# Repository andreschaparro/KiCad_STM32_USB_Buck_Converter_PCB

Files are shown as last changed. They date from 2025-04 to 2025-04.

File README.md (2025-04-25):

# KiCad STM32 + USB + Buck Converter PCB Design and JLCPCB Assembly

## Links

- [Fabricante de PCB](https://jlcpcb.com/).
- [Componentes](https://jlcpcb.com/parts).
- [Microcontrolador STM32 F4](https://jlcpcb.com/partdetail/Stmicroelectronics-STM32F405RGT6/C15742).
- [Conversor Buck](https://jlcpcb.com/partdetail/Monolithic_PowerSystems-MP2359DJ_LFZ/C14259).
- [Protección ESD para el USB](https://jlcpcb.com/partdetail/Stmicroelectronics-USBLC62SC6/C7519).
- [Cristal 16Mhz](https://jlcpcb.com/partdetail/Yxc_CrystalOscillators-X322516MLB4SI/C13738).
- [Protección Polaridad Inversa](https://jlcpcb.com/partdetail/Alpha_OmegaSemicon-AO3401A/C15127).
- [Ferrite para Conversores Buck](https://jlcpcb.com/partdetail/Sunlord-GZ2012D601TF/C1017).
- [Diodo Schottky recomendado para Conversores Buck](https://jlcpcb.com/partdetail/mdd_microdiode_semiconductor-B5819W/C64885).
- [Inductor de potencia para Conversores Buck](https://jlcpcb.com/partdetail/Sunlord-MWSA0503S100MT/C408412).

❗Minimizar el uso de extended parts y usar las basic para minimizar el costo del PCB.

## STM32CubeIDE

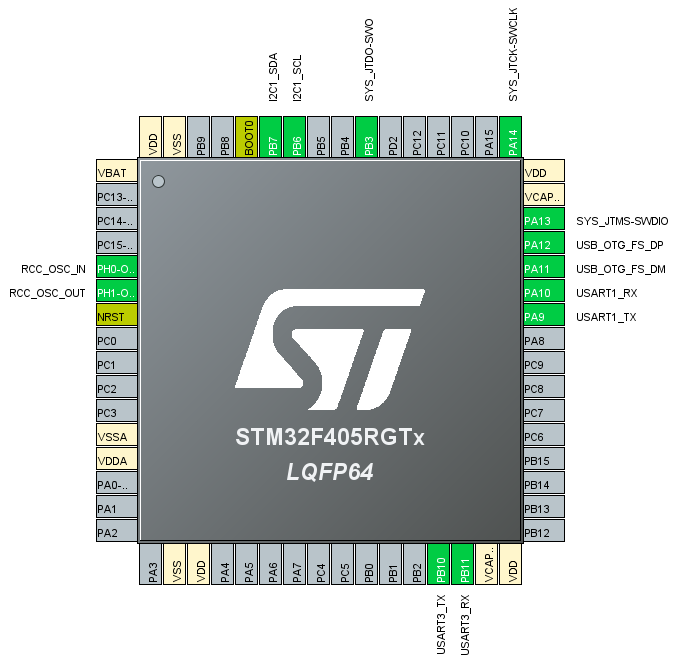
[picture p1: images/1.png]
Mala posición de la USART1


📝En lo posible, colocar los buses de comunicación en distintos laterales del microcontrolador. Y si no se puede, colocarlos lo mas separados que se pueda dentro del mismo lateral.

❗En la imagen, se ve una mala ubicación para la USART1 porque queda muy cerca del USB_FS. Para solucionar el problema, utilizar la USART3 que esta en otro lateral.

## Opciones para interconectar VDD con VDDA

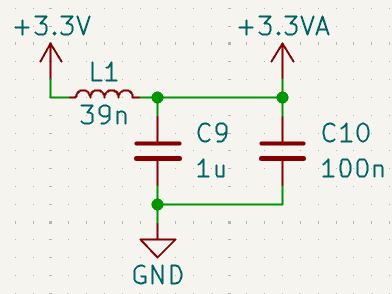
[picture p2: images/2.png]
Filtro LC


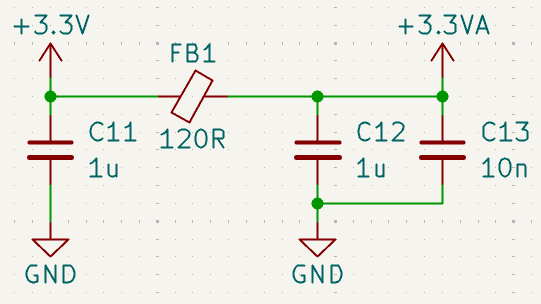
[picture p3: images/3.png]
Ferrite


## Cortex Debug Connector (10-pins, 0.05")

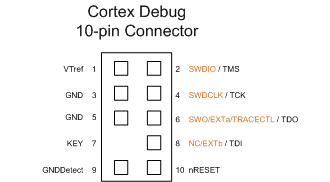
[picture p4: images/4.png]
Conector para debug


## Apilado estándar de 4 capas de JLCPCB

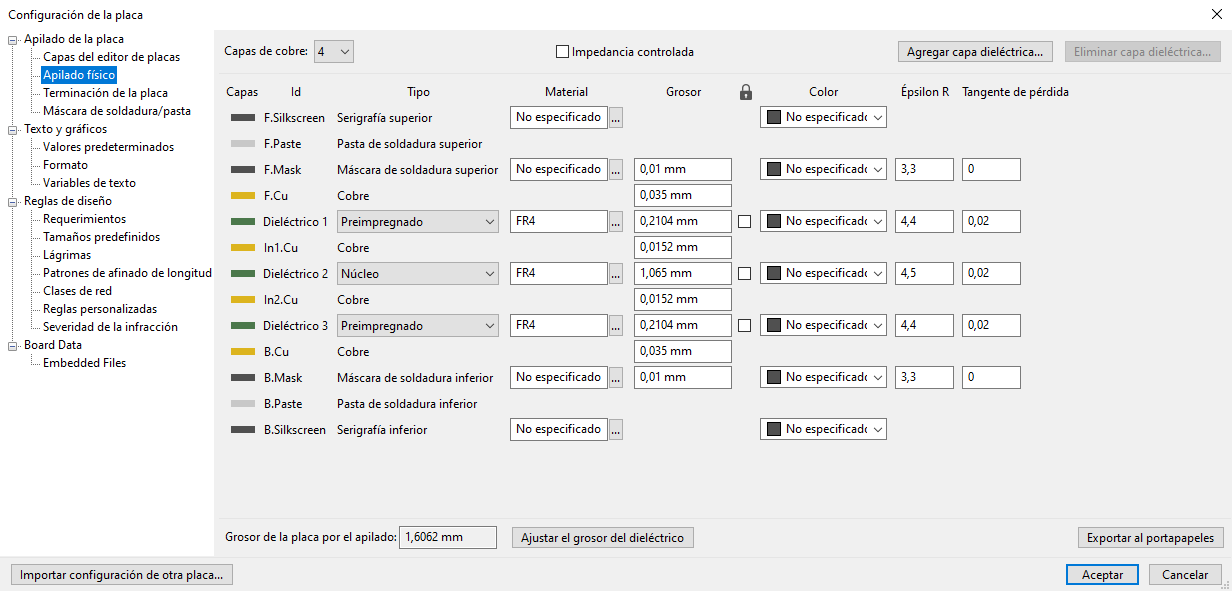
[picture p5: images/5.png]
Apilado


## Reglas de diseño JLCPCB

[Fabricante de PCB](https://jlcpcb.com/capabilities/pcb-capabilities).

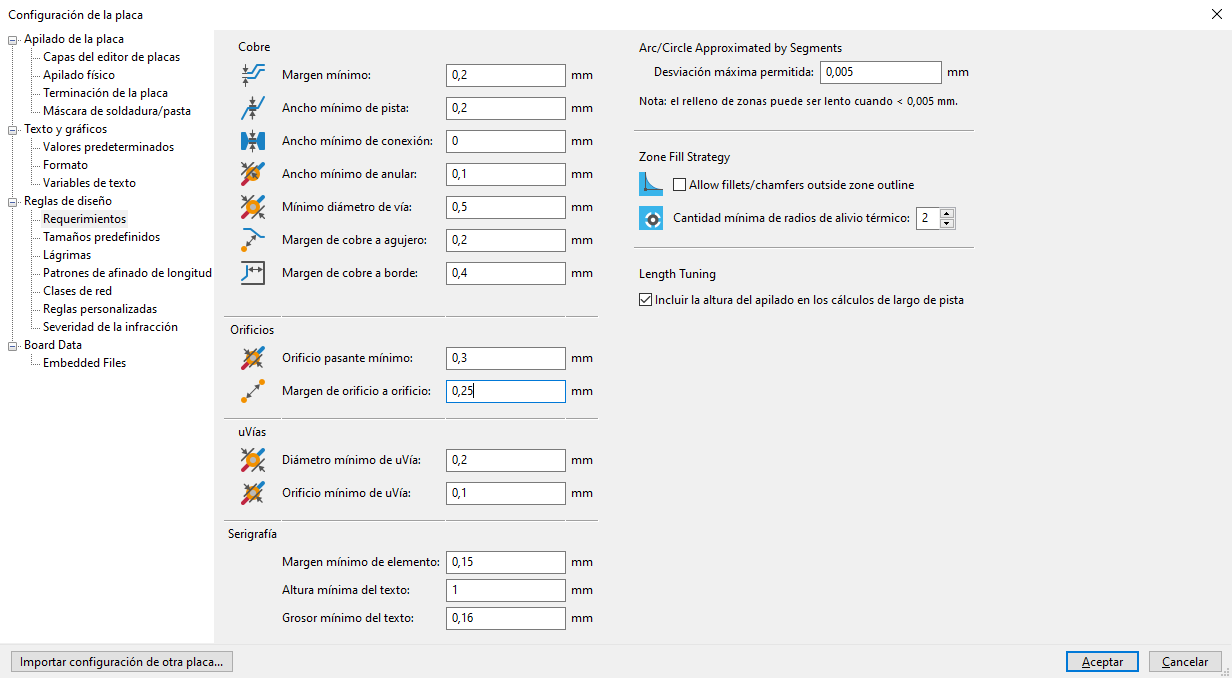
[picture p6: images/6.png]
Reglas de diseño


## Pasos para armar el Layout

📝Trabajar con una grilla de 1mm o 0,25mm.

❗Si hay restricciones mecánicas, primero dibujar el borde de la placa y posicionar agujeros de montaje.

1. Colocar el microcontrolador.
2. Separar los componentes en grupos funcionales.
3. Colocar los capacitores de desacople de 100n lo mas cerca posible del microcontrolador.
4. Colocar el filtro de conexión entre VDD y VDDA lo mas cerca posible del microcontrolador.
5. Colocar los capacitores de VCAP_1 y VCAP_2 lo mas cerca posible del microcontrolador.
6. Colocar el circuito del cristal lo mas cerca posible del microcontrolador.
7. Colocar el capacitor de desacople de 4u7 o 10u cerca del capacitor de 100n que está más alejado de la salida del regulador Buck.

📝Medir distancias con la regla.

8. Colocar elementos del BOOT0.
9. Colocar el led de status.
10. Colocar el conector USB (con su protección ESD lo más cerca posible).
11. Colocar el conector de la UART.
12. Colocar el conector I2C y sus resistencia (más cerca del host que del conector).
13. Colocar los conectores de Debug y +12V.
14. Colocar todos los componentes del circuito de alimentación dentro de un área pequeña.

📝Utilizar el layout sugerido en la hoja de datos del conversor Buck.
📝Si no hay layout sugerido, los componentes de la red de realimentación deben estar cerca del conversor Buck.
📝Si no hay layout sugerido, los componentes de la red de filtrado deben estar cercanos entre sí y del conversor Buck.
📝Si hubiese señales análogicas, deberían estar bastante separadas del área del conversor Buck.

15. Colocar leds indicadores de alimentación.
16. Colocar los agujeros de montaje.
17. Dibujar el borde de la placa.
18. Ajustar conectores y otros elementos utilizando la perspectiva 3D de KiCad.

❗JLCPCB no utiliza las capas F.Fab y B.Fab. Por lo que se puede, enviar la númeración de componetes al F.Fab para ahorrar espacio.

## Pasos para el ruteo

📝Un ancho de pista de 0,3mm es práctico para hacer conexiones directa con el microcontrolador.

1. Capacitores de desacople.
2. La pista de HSE_IN debe pasar por el medio del cristal.

📝Corregir la posición vertical del cristal manualmente.

3. Todas las conexiones del circuito del cristal deben realizarse en el top layer.
4. Las pistas I2C_SDA e I2C_SDL deben separarse al menos 2 a 3 veces su ancho, y lo mas cerca posible del microcontrolador para evitar Crosstalk.
5. Las pistas TX y RX de una USART deben separarse con el mismo criterio que las de I2C.
6. Las pistas de Debug son de baja frecuencia.

❗Las pistas de baja frecuencia se pueden pasar por el bottom layer mediante vías y deben ser lo mas cortas posibles.

7. Para las pistas del circuito de alimentación, se pueden utilizar zonas de cobre o pistas gruesas.

📝La herramienta de cálculo de KiCad permite estimar la corriente que puede circular por una pista.

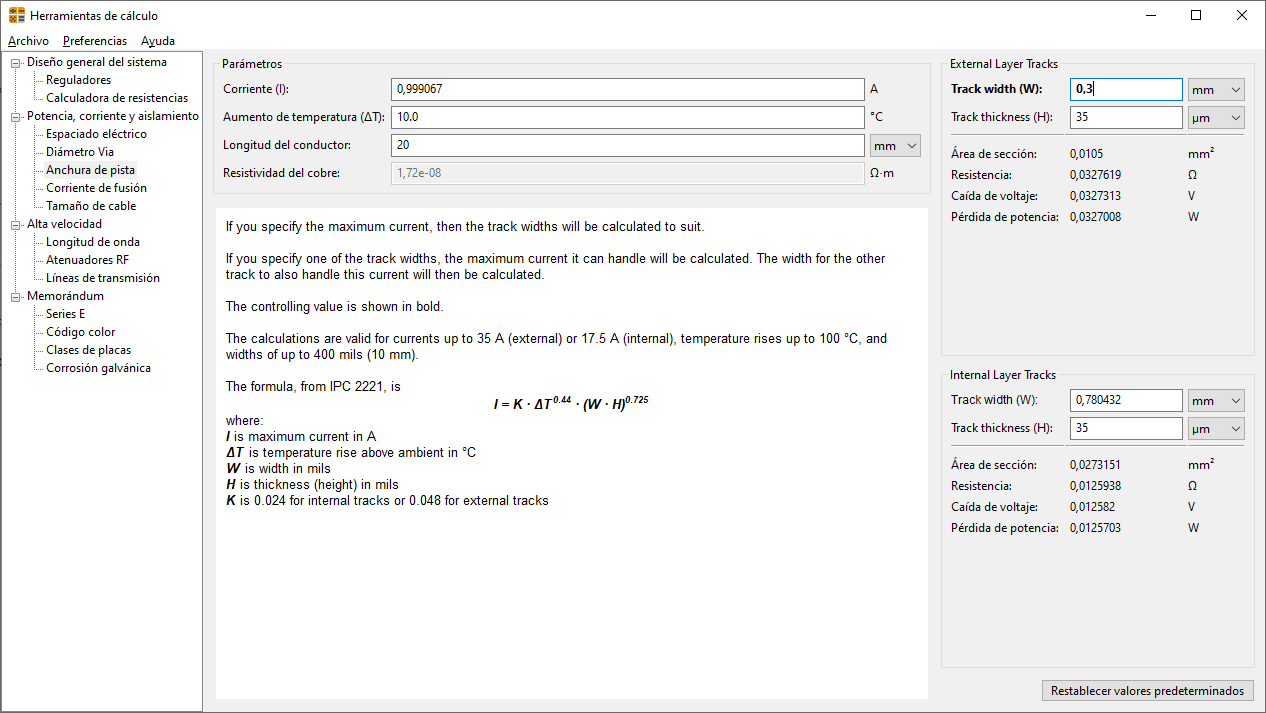
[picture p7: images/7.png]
Anchura de pista


8. Las pistas USB son un par diferencial con impedancia controlada de 90.

📝Utilizar la herramienta [JLCPCB Impedance Calculator](https://jlcpcb.com/pcb-impedance-calculator) no la de KiCad.

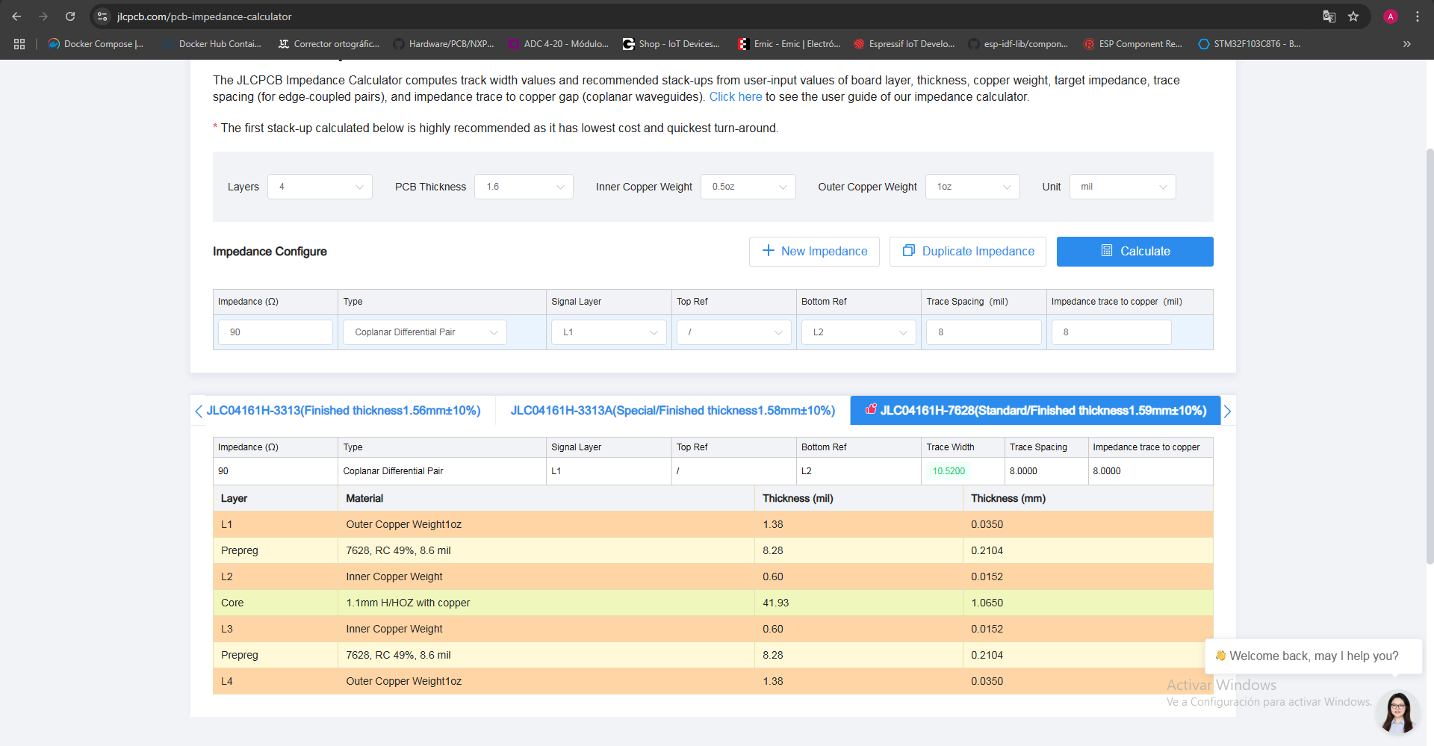
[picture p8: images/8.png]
JLCPCB Impedance Calculator


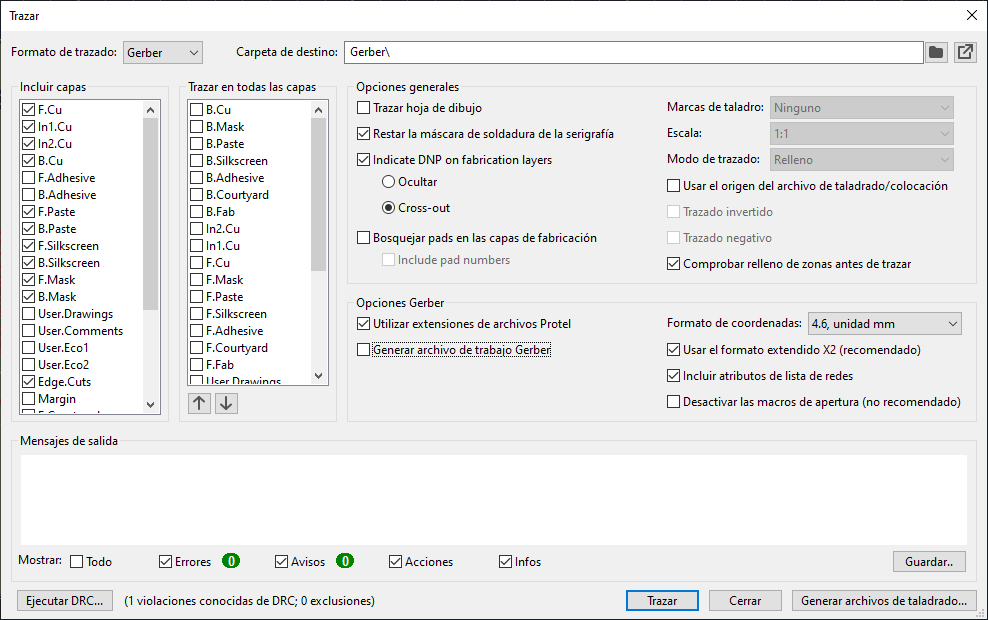
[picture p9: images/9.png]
Tamaños predefinidos


9. La pista de BOOT0 es de baja frecuencia.
10. Realizar las conexiones con los planos de GND y +3.3V con vías de 0,8mm/0,4mm.

❗Las vías deben colocarse lo mas cerca posible sin tocar los pads para minimizar la resistencia e inductancia parásita.

📝Puede que haga falta más de una vía en función de la corriente.

❗Para la conexión entre VDD y VDDA poner al menos 2 vías para minimizar la resistencia e inductancia parásita.

❗Conectar las vías a los pads con trazos cortos y anchos (0,5mm o más).

❗En el regulador Buck utilizar al menos 2 vías por pad. Excepto, en el inductor donde conviene que tenga al menos 4.

❗En el GND del USB poner al menos 4 vías.

11. Agregar serigrafía:

- Función de los conectores.
- Función de los leds.
- Pin positivo de diodos y capacitores.
- Pin número 1 de los circuitos integrados.
- Nombre de la placa.
- Logo.

## Manufactura

1. Agregar el texto `JLCJLCJLCJLC` en el layer F.Silkscreen.

📝[How to mark on PCB?](https://jlcpcb.com/help/article/How-to-remove-order-number-from-your-PCB)

2. Agregar 3 o 4 tooling holes.

❗Son circulos de radio 0,576mm hechos en el layer Edge.Cuts.

❗Los mismos deben hubicarse en esquinas opuestas de la placa y lo más apartados uno del otro.

📝[How to add tooling holes for PCB assembly order](https://jlcpcb.com/help/article/How-to-add-tooling-holes-for-PCB-assembly-order)

3. Generar los gerbers.

Gerbers

4. Generar los drill files.
5. Comprimir los gerbers junto a los drill files.

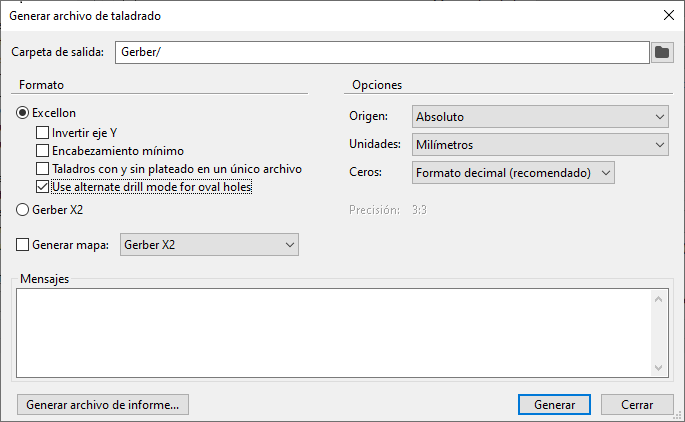
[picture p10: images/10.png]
Drill Files


📝[How to Prepare Gerber Files Before Placing Orders?](https://jlcpcb.com/help/article/gerber-files-preparation)

📝[How to generate Gerber and Drill files in KiCAD 8?](https://jlcpcb.com/help/article/how-to-generate-gerber-and-drill-files-in-kicad-8)

6. Generar los pick and place files.

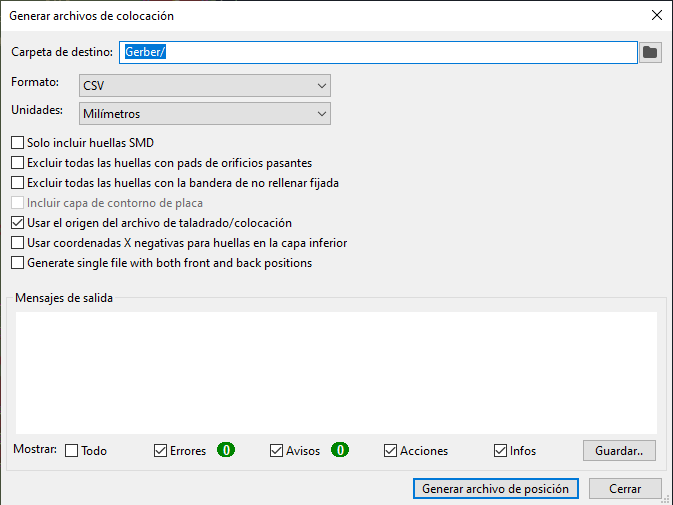
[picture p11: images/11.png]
Pick and Place files


7. Modificar el nombre de las columnas de los pick and place files.

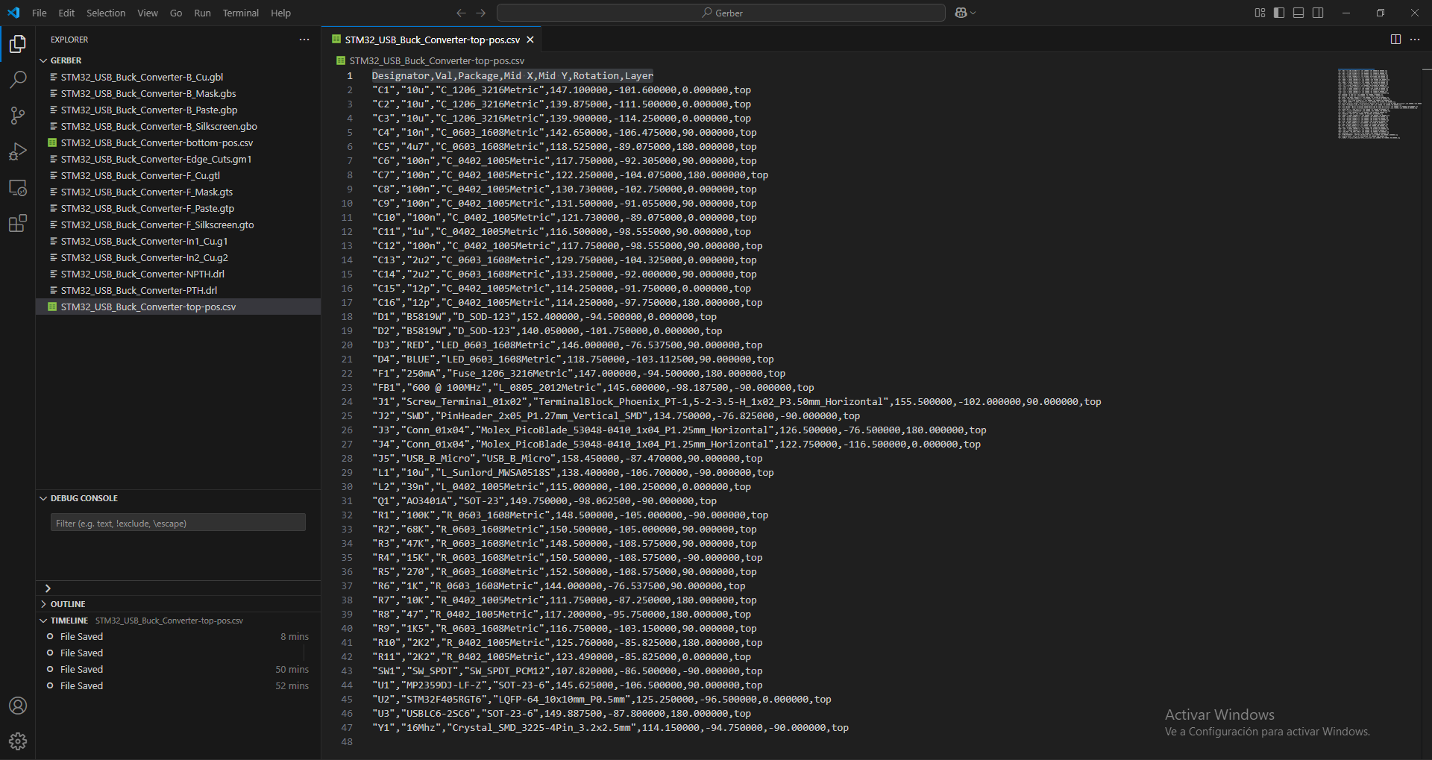
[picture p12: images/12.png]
CSV corregido


8. Abrir el editor de esquemas y agregarle a los símbolos un campo llamado `JLCPCB Part #`.
9. Ingresar el `JLCPCB Part #` de cada componente.

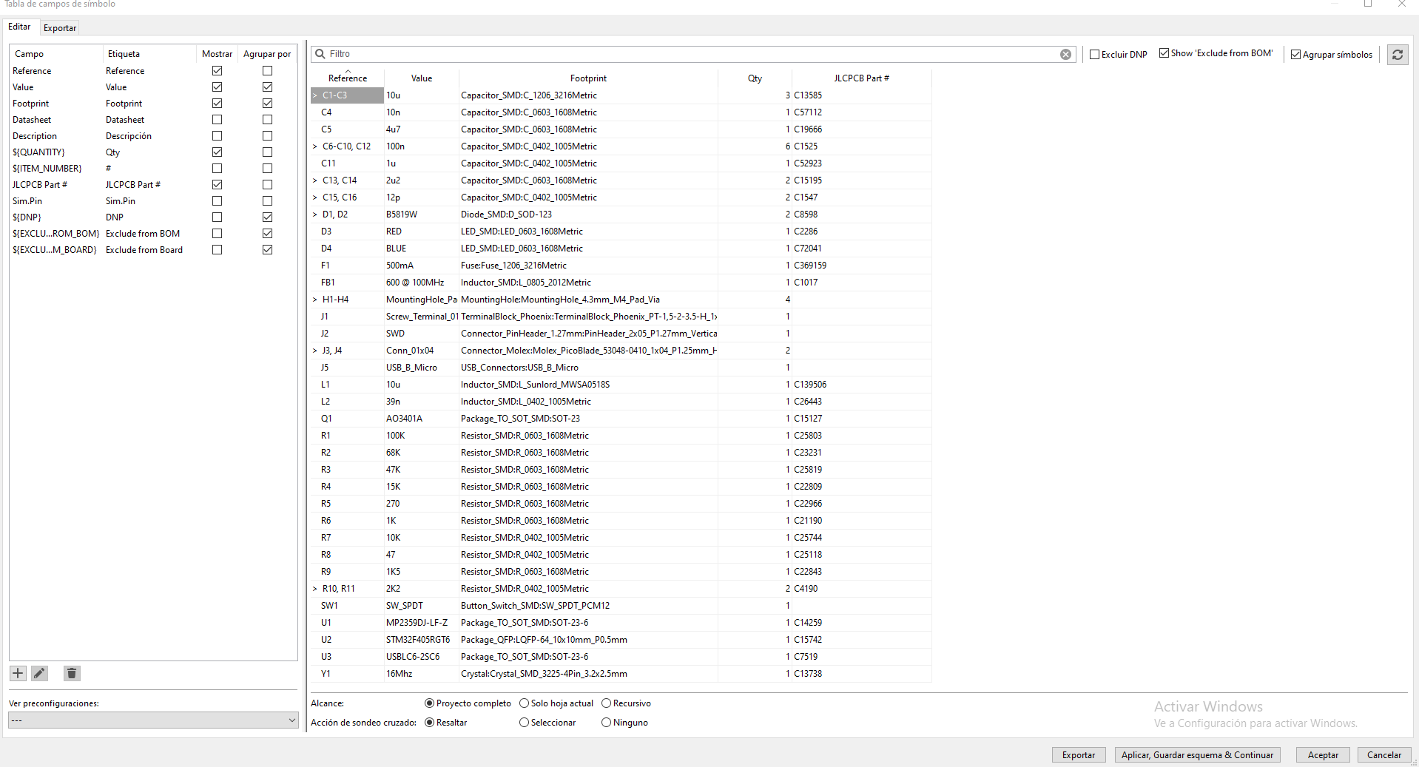
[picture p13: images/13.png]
JLCPCB Part #


❗Por el momento JLCPCB no ofrece componentes THT. Los mismos, deberán ser comprados por [LCSC](https://www.lcsc.com/) y soldados manualmente.

10. Instalar la extensión `JLC PCB abrication Toolkit` de KiCad.
11. Abrir el editor de placas y generar el BOM.

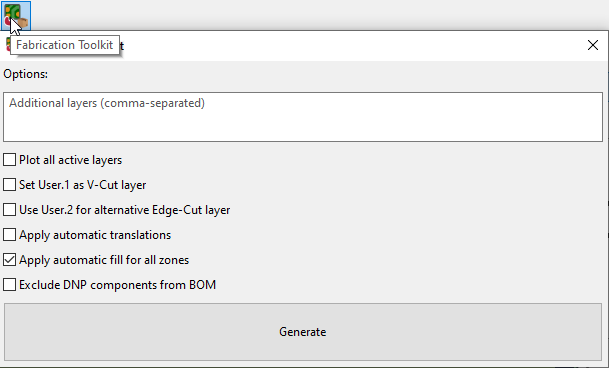
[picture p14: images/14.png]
Generar el BOM


❗Con esta extensión se crea una carpeta llamada production con todos los archivos para la producción y dentro de ellos el BOM.

📝[Pick & Place File for PCB Assembly](https://jlcpcb.com/help/article/pick-place-file-for-pcb-assembly).

📝[Bill of Materials(BOM) File for PCB Assembly](https://jlcpcb.com/help/article/bill-of-materials-for-pcb-assembly)

📝[How to generate the BOM and Centroid file from KiCAD](https://jlcpcb.com/help/article/How-to-generate-the-BOM-and-Centroid-file-from-KiCAD).

12. Crear una cuenta en la página del fabricante.
13. Cargar los archivos y verificar la orientación de los componentes.

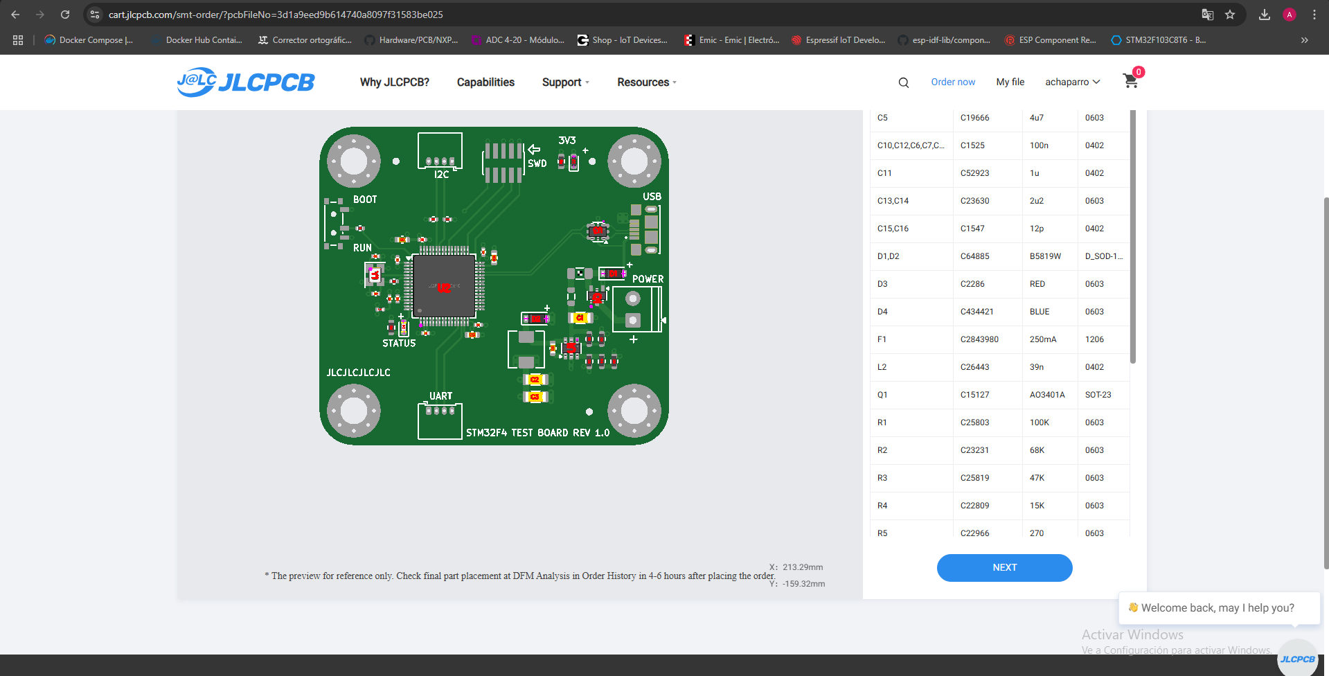
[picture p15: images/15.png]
PCB con errores


❗En la imagen se ve que hay que rotar: U2 -90°, U1 -180°, Q1 -180°, U3 -90°.

📝Cuando se rota un componente, un ángulo positivo es en contra de las agujas del reloj. Y un ángulo negativo en el sentido de las agujas del reloj.

14. Corregir la orientación de los componentes en los pick and place files.
15. Repetir el paso 12.

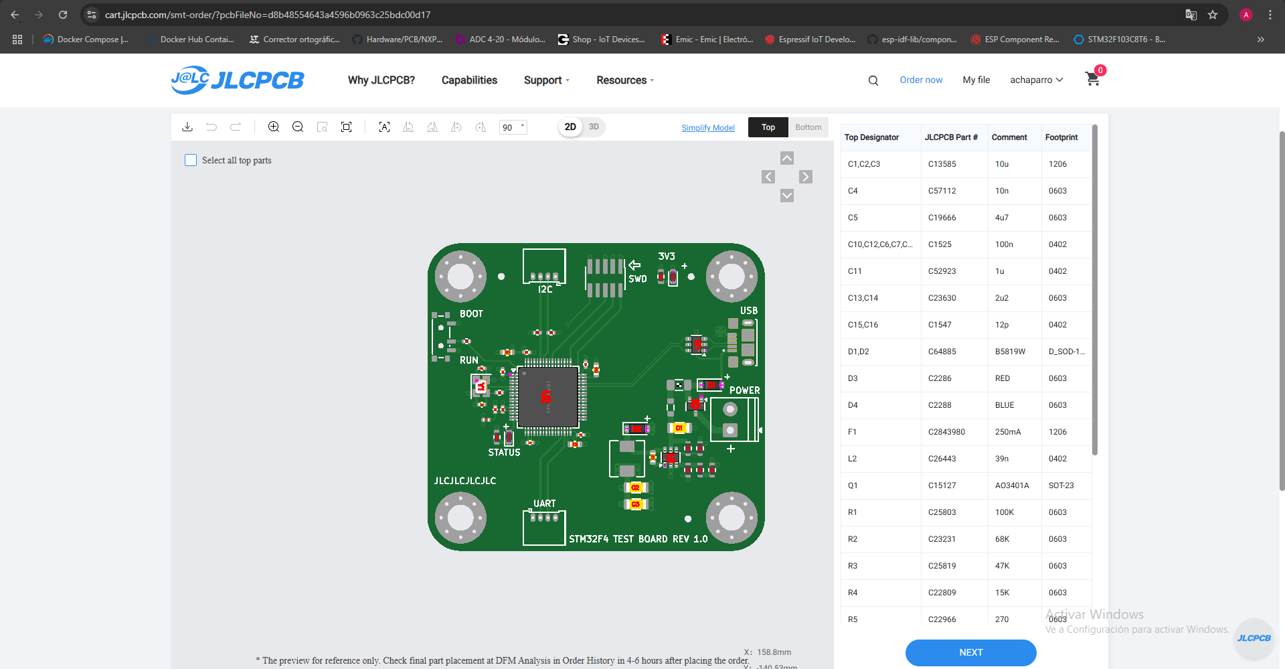
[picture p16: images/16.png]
PCB corregido


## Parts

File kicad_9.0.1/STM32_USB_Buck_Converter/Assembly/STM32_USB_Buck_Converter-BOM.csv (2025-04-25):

Designator | Footprint | Quantity | Value | LCSC Part #
C1, C2, C3 | 1206 | 3 | 10u
C10, C12, C6, C7, C8, C9 | 0402 | 6 | 100n
C11 | 0402 | 1 | 1u
C13, C14 | 0603 | 2 | 2u2
C15, C16 | 0402 | 2 | 12p
C4 | 0603 | 1 | 10n
C5 | 0603 | 1 | 4u7
D1, D2 | D_SOD-123 | 2 | B5819W
D3 | 0603 | 1 | RED
D4 | 0603 | 1 | BLUE
F1 | 1206 | 1 | 250mA
FB1 | 0805 | 1 | 600 @ 100MHz
J1 | TerminalBlock_Phoenix_PT-1,5-2-3.5-H_1x02_P3.50mm_Horizontal | 1 | Screw_Terminal_01x02
J2 | PinHeader_2x05_P1.27mm_Vertical_SMD | 1 | SWD
J3, J4 | Molex_PicoBlade_53048-0410_1x04_P1.25mm_Horizontal | 2 | Conn_01x04
J5 | USB_B_Micro | 1 | USB_B_Micro
L1 | L_Sunlord_MWSA0518S | 1 | 10u
L2 | 0402 | 1 | 39n
Q1 | SOT-23 | 1 | AO3401A
R1 | 0603 | 1 | 100K
R10, R11 | 0402 | 2 | 2K2
R2 | 0603 | 1 | 68K
R3 | 0603 | 1 | 47K
R4 | 0603 | 1 | 15K
R5 | 0603 | 1 | 270
R6 | 0603 | 1 | 1K
R7 | 0402 | 1 | 10K
R8 | 0402 | 1 | 47
R9 | 0603 | 1 | 1K5
SW1 | SW_SPDT_PCM12 | 1 | SW_SPDT
U1 | SOT-23-6 | 1 | MP2359DJ-LF-Z
U2 | LQFP-64_10x10mm_P0.5mm | 1 | STM32F405RGT6
U3 | SOT-23-6 | 1 | USBLC6-2SC6
Y1 | Crystal_SMD_3225-4Pin_3.2x2.5mm | 1 | 16Mhz

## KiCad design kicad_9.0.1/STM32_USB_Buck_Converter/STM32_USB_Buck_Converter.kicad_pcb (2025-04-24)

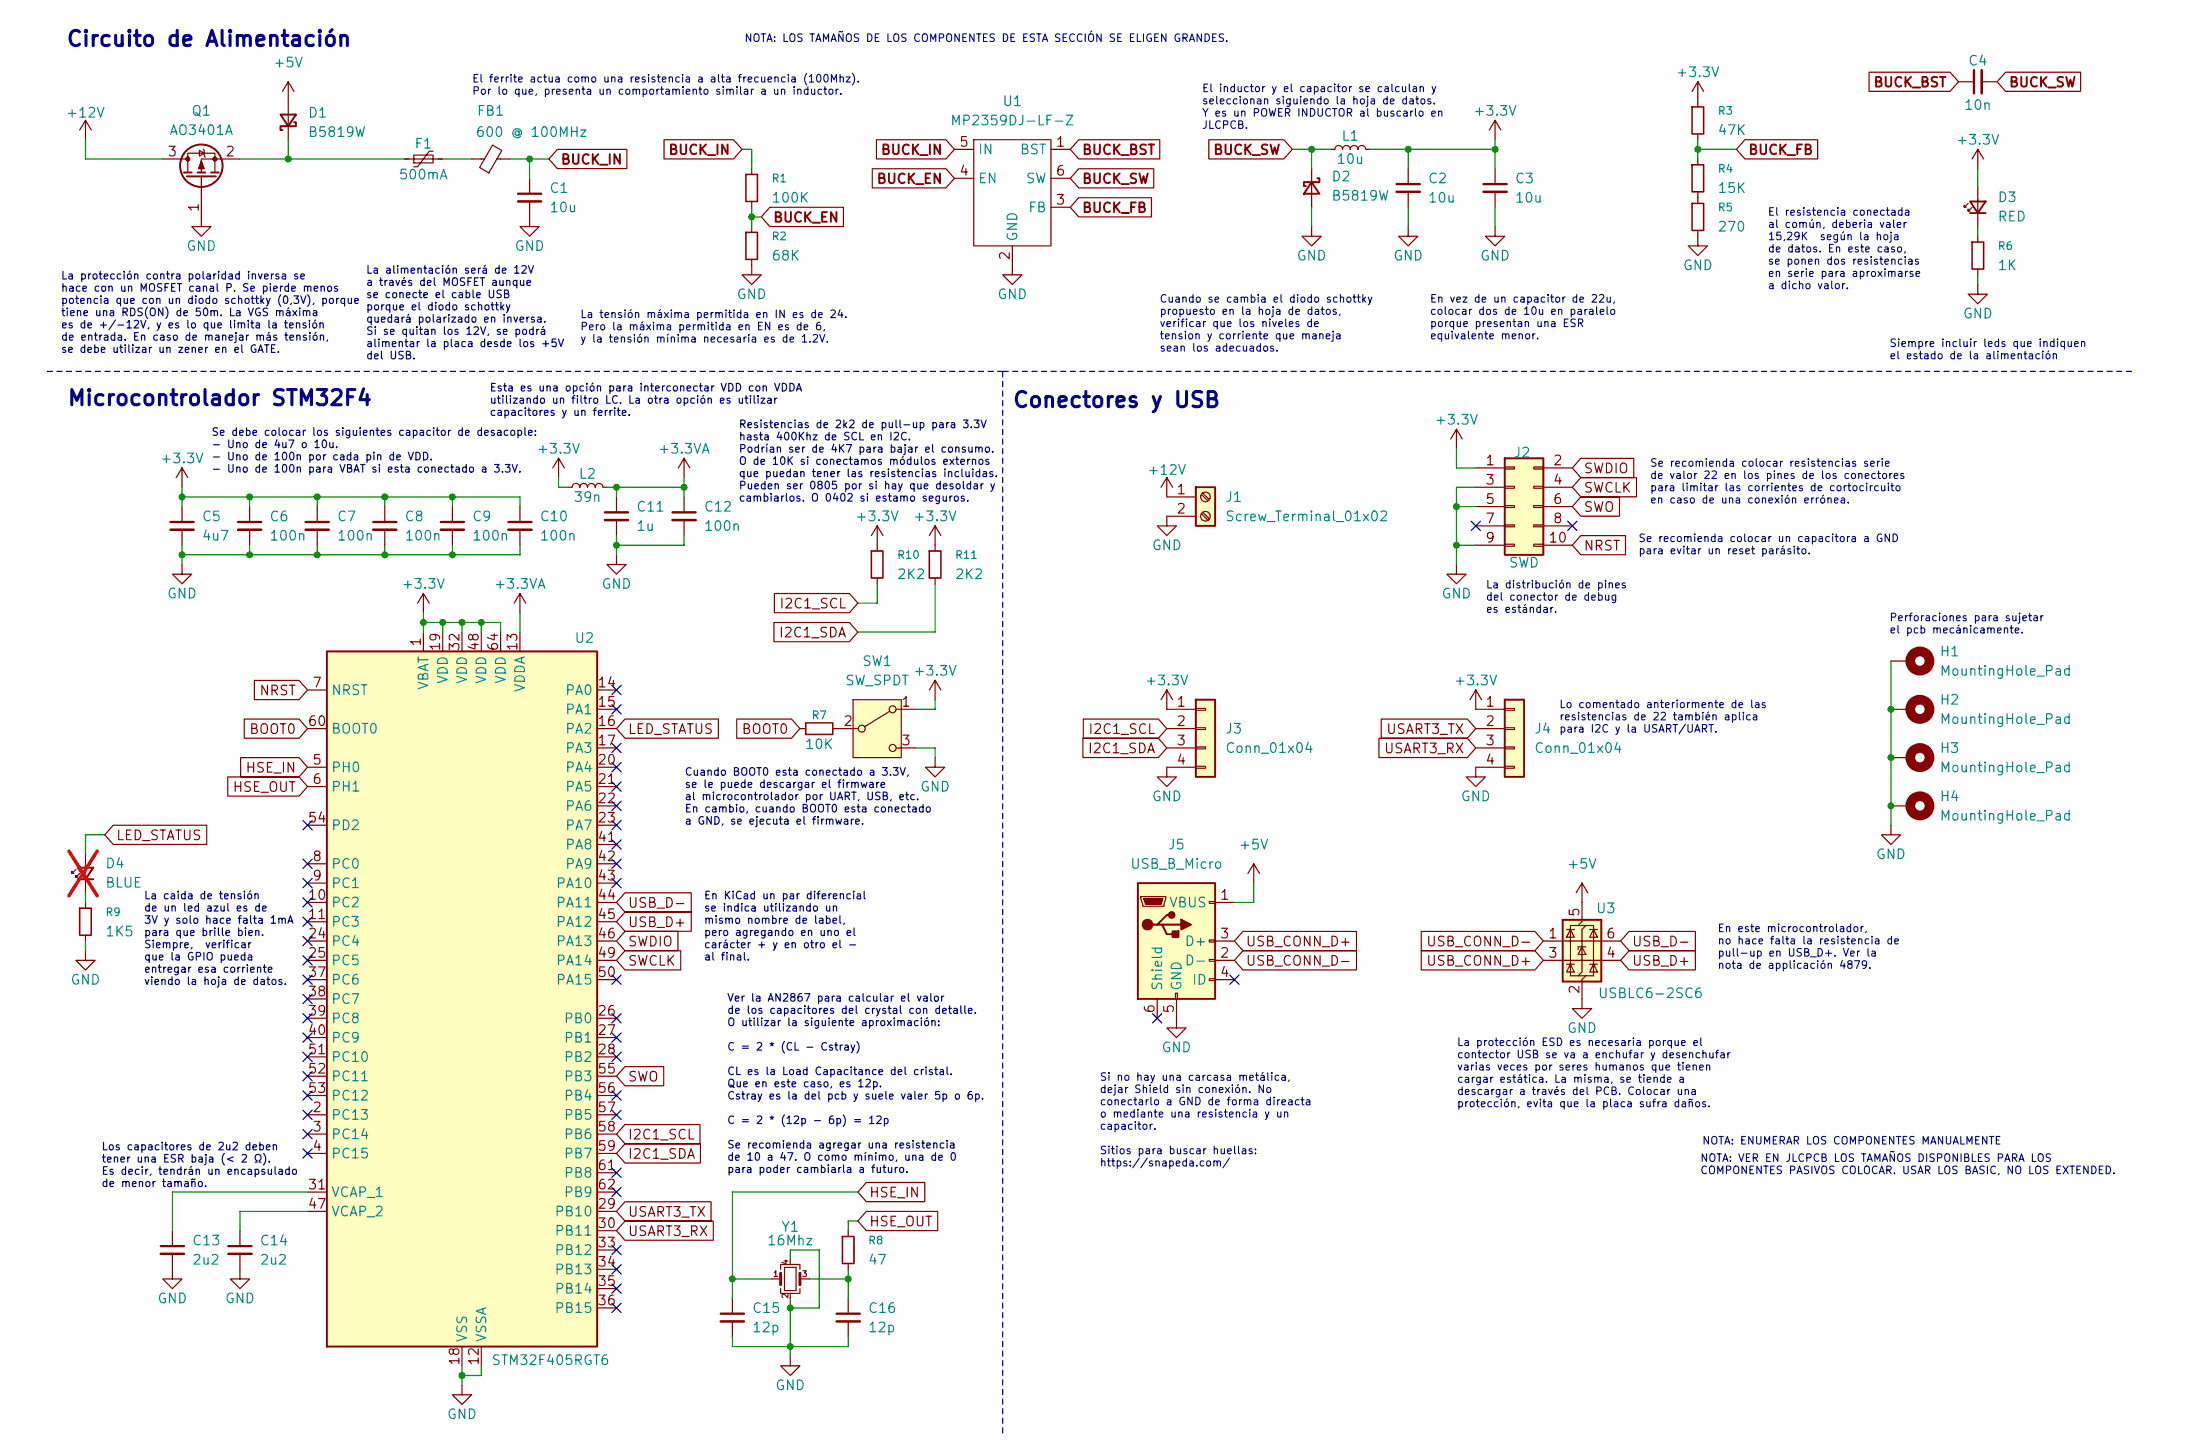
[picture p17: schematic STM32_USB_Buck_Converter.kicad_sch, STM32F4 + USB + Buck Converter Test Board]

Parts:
C1, C2, C3: 10u; C_1206_3216Metric; JLCPCB Part # C13585
C4: 10n; C_0603_1608Metric; JLCPCB Part # C57112
C5: 4u7; C_0603_1608Metric; JLCPCB Part # C19666
C6, C7, C8, C9, C10, C12: 100n; C_0402_1005Metric; JLCPCB Part # C1525
C11: 1u; C_0402_1005Metric; JLCPCB Part # C52923
C13, C14: 2u2; C_0603_1608Metric; JLCPCB Part # C15195
C15, C16: 12p; C_0402_1005Metric; JLCPCB Part # C1547
D1, D2: B5819W; D_SOD-123; JLCPCB Part # C8598
D3: RED; LED_0603_1608Metric; JLCPCB Part # C2286
D4: BLUE; LED_0603_1608Metric; JLCPCB Part # C72041; not fitted
F1: 500mA; Fuse_1206_3216Metric; JLCPCB Part # C369159
FB1: 600 @ 100MHz; L_0805_2012Metric; JLCPCB Part # C1017
H1, H2, H3, H4: MountingHole_Pad; MountingHole_4.3mm_M4_Pad_Via
J1: Screw_Terminal_01x02; TerminalBlock_Phoenix_PT-1,5-2-3.5-H_1x02_P3.50mm_Horizontal
J2: SWD; PinHeader_2x05_P1.27mm_Vertical_SMD
J3, J4: Conn_01x04; Molex_PicoBlade_53048-0410_1x04_P1.25mm_Horizontal
J5: USB_B_Micro
L1: 10u; L_Sunlord_MWSA0518S; JLCPCB Part # C139506
L2: 39n; L_0402_1005Metric; JLCPCB Part # C26443
Q1: AO3401A; SOT-23; JLCPCB Part # C15127
R1: 100K; R_0603_1608Metric; JLCPCB Part # C25803
R2: 68K; R_0603_1608Metric; JLCPCB Part # C23231
R3: 47K; R_0603_1608Metric; JLCPCB Part # C25819
R4: 15K; R_0603_1608Metric; JLCPCB Part # C22809
R5: 270; R_0603_1608Metric; JLCPCB Part # C22966
R6: 1K; R_0603_1608Metric; JLCPCB Part # C21190
R7: 10K; R_0402_1005Metric; JLCPCB Part # C25744
R8: 47; R_0402_1005Metric; JLCPCB Part # C25118
R9: 1K5; R_0603_1608Metric; JLCPCB Part # C22843
R10, R11: 2K2; R_0402_1005Metric; JLCPCB Part # C4190
SW1: SW_SPDT; SW_SPDT_PCM12
U1: MP2359DJ-LF-Z; SOT-23-6; JLCPCB Part # C14259
U2: STM32F405RGT6; LQFP-64_10x10mm_P0.5mm; JLCPCB Part # C15742
U3: USBLC6-2SC6; SOT-23-6; JLCPCB Part # C7519
Y1: 16Mhz; Crystal_SMD_3225-4Pin_3.2x2.5mm; JLCPCB Part # C13738

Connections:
+3.3V: C2.1, C3.1, C5.1, C6.1, C7.1, C8.1, C9.1, C10.1, D3.2 (A), J2.1, J3.1, J4.1, L1.2, L2.1, R3.1, R10.1, R11.1, SW1.1 (A), U2.1 (VBAT), U2.19 (VDD), U2.32 (VDD), U2.48 (VDD), U2.64 (VDD)
+3.3VA: C11.1, C12.1, L2.2, U2.13 (VDDA)
+5V: D1.2 (A), J5.1 (VBUS), U3.5 (VBUS)
+12V: J1.1, Q1.3 (D)
BOOT0: R7.1, U2.60 (BOOT0)
BUCK_BST: C4.1, U1.1 (BST)
BUCK_EN: R1.2, R2.1, U1.4 (EN)
BUCK_FB: R3.2, R4.1, U1.3 (FB)
BUCK_IN: C1.1, FB1.2, R1.1, U1.5 (IN)
BUCK_SW: C4.2, D2.1 (K), L1.1, U1.6 (SW)
GND: C1.2, C2.2, C3.2, C5.2, C6.2, C7.2, C8.2, C9.2, C10.2, C11.2, C12.2, C13.2, C14.2, C15.2, C16.2, D2.2 (A), H1.1, H2.1, H3.1, H4.1, J1.2, J2.3, J2.5, J2.9, J3.4, J4.4, J5.5 (GND), Q1.1 (G), R2.2, R5.2, R6.2, R9.2, SW1.3 (C), U1.2 (GND), U2.12 (VSSA), U2.18 (VSS), U2.63 (VSS), U3.2 (GND), Y1.2, Y1.4
HSE_IN: C15.1, U2.5 (PH0), Y1.1
HSE_OUT: R8.1, U2.6 (PH1)
I2C1_SCL: J3.2, R10.2, U2.58 (PB6)
I2C1_SDA: J3.3, R11.2, U2.59 (PB7)
LED_STATUS: D4.2 (A), U2.16 (PA2)
NRST: J2.10, U2.7 (NRST)
unnamed: C16.1, R8.2, Y1.3
unnamed: D1.1 (K), F1.1, Q1.2 (S)
unnamed: D3.1 (K), R6.1
unnamed: D4.1 (K), R9.1
unnamed: F1.2, FB1.1
unnamed: R4.2, R5.1
unnamed: R7.2, SW1.2 (B)
unnamed: C13.1, U2.31 (VCAP_1)
unnamed: C14.1, U2.47 (VCAP_2)
SWCLK: J2.4, U2.49 (PA14)
SWDIO: J2.2, U2.46 (PA13)
SWO: J2.6, U2.55 (PB3)
USART3_RX: J4.3, U2.30 (PB11)
USART3_TX: J4.2, U2.29 (PB10)
USB_CONN_D+: J5.3 (D+), U3.3 (I/O2)
USB_CONN_D-: J5.2 (D-), U3.1 (I/O1)
USB_D+: U2.45 (PA12), U3.4 (I/O2)
USB_D-: U2.44 (PA11), U3.6 (I/O1)

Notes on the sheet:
En este microcontrolador, no hace falta la resistencia de pull-up en USB_D+. Ver la nota de applicación 4879.
En KiCad un par diferencial se indica utilizando un mismo nombre de label, pero agregando en uno el carácter + y en otro el - al final.
Resistencias de 2k2 de pull-up para 3.3V hasta 400Khz de SCL en I2C. Podrían ser de 4K7 para bajar el consumo. O de 10K si conectamos módulos externos que puedan tener las resistencias incluidas. Pueden ser 0805 por si hay que desoldar y cambiarlos. O 0402 si estamo seguros.
Se recomienda colocar resistencias serie de valor 22 en los pines de los conectores para limitar las corrientes de cortocircuito en caso de una conexión errónea.
La protección contra polaridad inversa se hace con un MOSFET canal P. Se pierde menos potencia que con un diodo schottky (0,3V), porque tiene una RDS(ON) de 50m. La VGS máxima es de +/-12V, y es lo que limita la tensión de entrada. En caso de manejar más tensión, se debe utilizar un zener en el GAT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
La tensión máxima permitida en IN es de 24. Pero la máxima permitida en EN es de 6, y la tensión mínima necesaria es de 1.2V.
Los capacitores de 2u2 deben tener una ESR baja (< 2 Ω). Es decir, tendrán un encapsulado de menor tamaño.
NOTA: LOS TAMAÑOS DE LOS COMPONENTES DE ESTA SECCIÓN SE ELIGEN GRANDES.
Se recomienda colocar un capacitora a GND para evitar un reset parásito.
Esta es una opción para interconectar VDD con VDDA utilizando un filtro LC. La otra opción es utilizar capacitores y un ferrite.
Cuando BOOT0 esta conectado a 3.3V, se le puede descargar el firmware al microcontrolador por UART, USB, etc. En cambio, cuando BOOT0 esta conectado a GND, se ejecuta el firmware.
La alimentación será de 12V a través del MOSFET aunque se conecte el cable USB porque el diodo schottky quedará polarizado en inversa. Si se quitan los 12V, se podrá alimentar la placa desde los +5V del USB.
Ver la AN2867 para calcular el valor de los capacitores del crystal con detalle. O utilizar la siguiente aproximación: C = 2 * (CL - Cstray) CL es la Load Capacitance del cristal. Que en este caso, es 12p. Cstray es la del pcb y suele valer 5p o 6p. C = 2 * (12p - 6p) = 12p Se recomienda agregar un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
Perforaciones para sujetar el pcb mecánicamente.
El resistencia conectada al común, deberia valer 15,29K según la hoja de datos. En este caso, se ponen dos resistencias en serie para aproximarse a dicho valor.
La protección ESD es necesaria porque el contector USB se va a enchufar y desenchufar varias veces por seres humanos que tienen cargar estática. La misma, se tiende a descargar a través del PCB. Colocar una protección, evita que la placa sufra daños.
NOTA: ENUMERAR LOS COMPONENTES MANUALMENTE
Se debe colocar los siguientes capacitor de desacople: - Uno de 4u7 o 10u. - Uno de 100n por cada pin de VDD. - Uno de 100n para VBAT si esta conectado a 3.3V.
La distribución de pines del conector de debug es estándar.
Lo comentado anteriormente de las resistencias de 22 también aplica para I2C y la USART/UART.
Conectores y USB
NOTA: VER EN JLCPCB LOS TAMAÑOS DISPONIBLES PARA LOS COMPONENTES PASIVOS COLOCAR. USAR LOS BASIC, NO LOS EXTENDED.
Cuando se cambia el diodo schottky propuesto en la hoja de datos, verificar que los niveles de tension y corriente que maneja sean los adecuados.
La caida de tensión de un led azul es de 3V y solo hace falta 1mA para que brille bien. Siempre, verificar que la GPIO pueda entregar esa corriente viendo la hoja de datos.
El inductor y el capacitor se calculan y seleccionan siguiendo la hoja de datos. Y es un POWER INDUCTOR al buscarlo en JLCPCB.
Siempre incluir leds que indiquen el estado de la alimentación
Circuito de Alimentación
El ferrite actua como una resistencia a alta frecuencia (100Mhz). Por lo que, presenta un comportamiento similar a un inductor.
En vez de un capacitor de 22u, colocar dos de 10u en paralelo porque presentan una ESR equivalente menor.
Microcontrolador STM32F4
Si no hay una carcasa metálica, dejar Shield sin conexión. No conectarlo a GND de forma direacta o mediante una resistencia y un capacitor. Sitios para buscar huellas: https://snapeda.com/

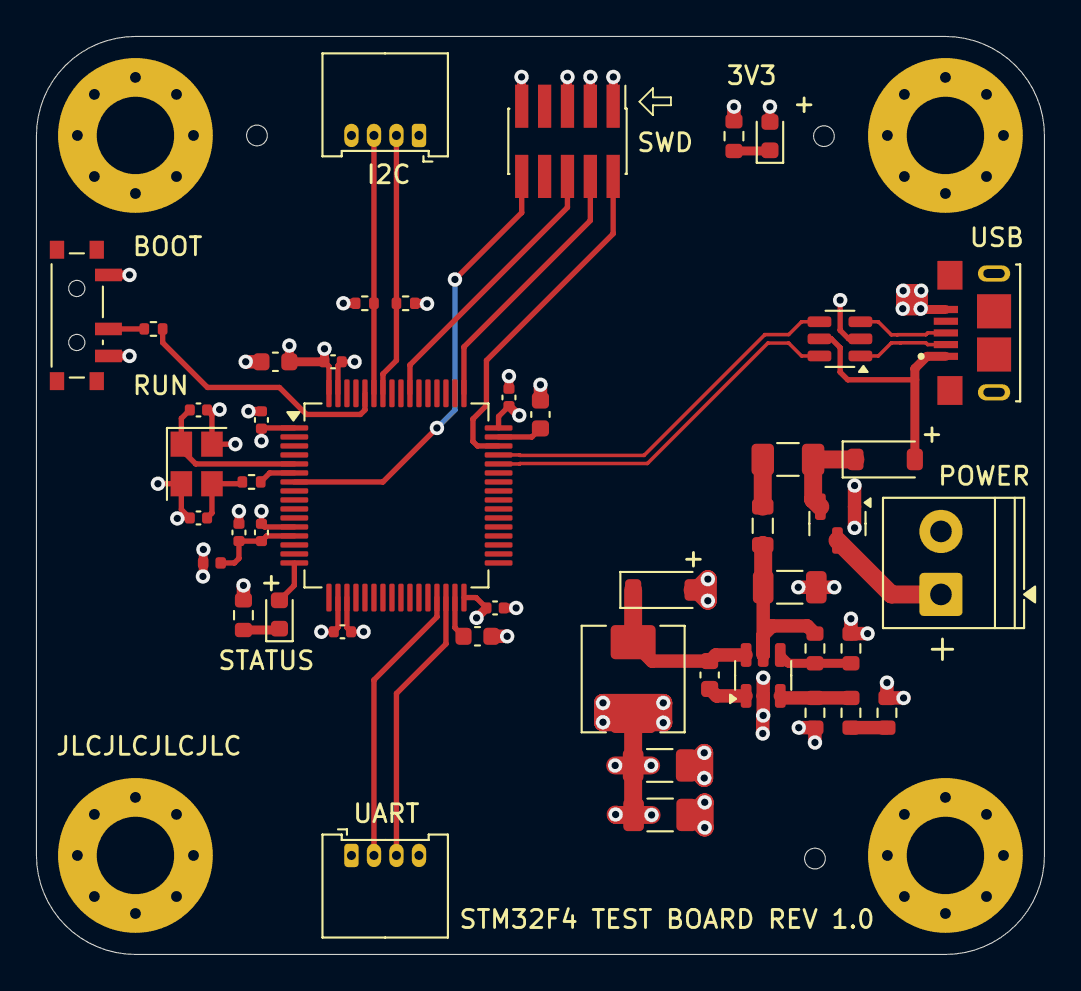
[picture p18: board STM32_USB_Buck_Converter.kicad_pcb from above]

Board: 4 copper layers, 56.0 x 51.0 mm, 50 parts (0 on the bottom side), 35 nets.

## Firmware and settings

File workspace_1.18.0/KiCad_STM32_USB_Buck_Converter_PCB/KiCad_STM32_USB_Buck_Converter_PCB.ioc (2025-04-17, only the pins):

Mcu.UserName=STM32F405RGTx
PA11.Signal=USB_OTG_FS_DM
PA12.Signal=USB_OTG_FS_DP
PA13.Signal=SYS_JTMS-SWDIO
PA14.Signal=SYS_JTCK-SWCLK
PA2.GPIO_Label=LED_STATUS
PA2.Signal=GPIO_Output
PB10.Signal=USART3_TX
PB11.Signal=USART3_RX
PB3.Signal=SYS_JTDO-SWO
PB6.Signal=I2C1_SCL
PB7.Signal=I2C1_SDA
PH0-OSC_IN.Signal=RCC_OSC_IN
PH1-OSC_OUT.Signal=RCC_OSC_OUT

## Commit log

2025-04-25 archivos de stm32cubeide corregidos
2025-04-25 csv agregados
    [STM32_USB_Buck_Converter-BOM.csv, STM32_USB_Buck_Converter-Position.csv, bom.csv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]
